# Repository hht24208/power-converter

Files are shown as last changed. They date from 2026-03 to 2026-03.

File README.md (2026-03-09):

# STM32 Kontrollü SEPIC Güç Dönüştürücü (Öğrenci Projesi)

Bu repo, güç elektroniği ve kontrol teorisi konseptlerini birleştirerek pratik bir donanıma dönüştürmeyi amaçlayan kişisel bir mühendislik projesidir. Temel hedef, geniş giriş voltajı aralıklarında çalışabilen, yazılım tabanlı (STM32) PID kontrolüne sahip bir SEPIC dönüştürücünün önce LTspice üzerinde matematiksel sınırlarını görmek, ardından gerçek donanımını inşa etmektir.

## 1. Güç Katı ve Donanım Mimarisi
Aşağıdaki şema, SEPIC topolojisinin güç katını ve temel geri besleme (feedback) yapısını göstermektedir. Sistemi mikrodenetleyici ile güvenli bir şekilde sürebilmek için **TC4427** gate sürücü entegresi kullanıldı. Akım ve gerilim okumaları ise **LM358** op-ampları ile STM32'nin ADC pinlerine uygun seviyelere çekildi.

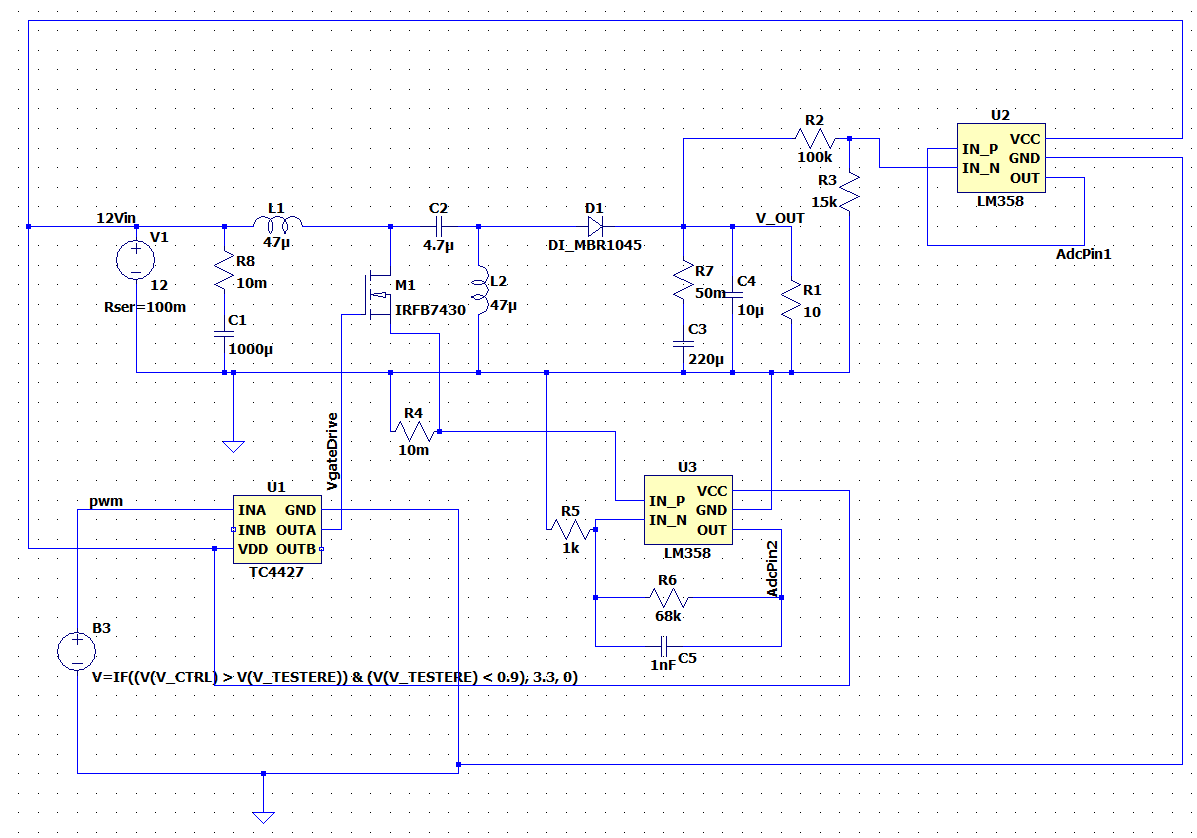
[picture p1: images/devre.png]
SEPIC Devre Şeması


## 2. Matematiksel Modelleme ve Kontrolcü Tasarımı
SEPIC dönüştürücüler 4. dereceden non-lineer sistemler olduğu ve sağ yarı düzlem sıfırı (RHPZ) barındırdığı için, sadece deneme-yanılma ile kontrol edilmeleri oldukça zordur. Bu projede işin teorik kısmına inilerek, sistemin transfer fonksiyonuna uygun bir **Type-II/III Kompansatör** mantığı araştırılmış ve LTspice üzerinde s-domain (Laplace) denklemleriyle modellenmiştir.

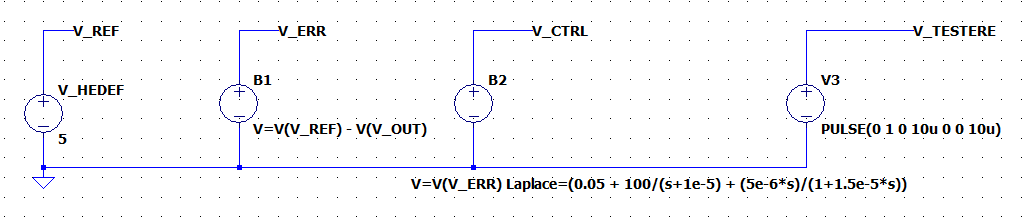
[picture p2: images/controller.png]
PID Kontrolcü ve Laplace Denklemi


## 3. Geçici Hal Yanıtı (Transient Response)
Aşağıdaki simülasyon çıktısında, sisteme aniden 12V giriş (Step Input) uygulandığında donanımın verdiği fiziksel tepki ve PID kontrolcünün davranışı incelenmiştir.
* Simülasyonun ilk milisaniyelerinde, SEPIC topolojisindeki uçan kondansatörün (flying capacitor) dolması sırasında oluşan doğal **Inrush Current (Başlangıç Şoku)** nedeniyle voltaj anlık olarak yükseliyor.
* Kontrolcü bu durumu yakalayarak PWM'i (Duty Cycle) %0'a çekiyor.
* Sistem yaklaşık 11. milisaniyede hedeflediğimiz **5V** seviyesine başarıyla oturarak regülasyonu sağlıyor.

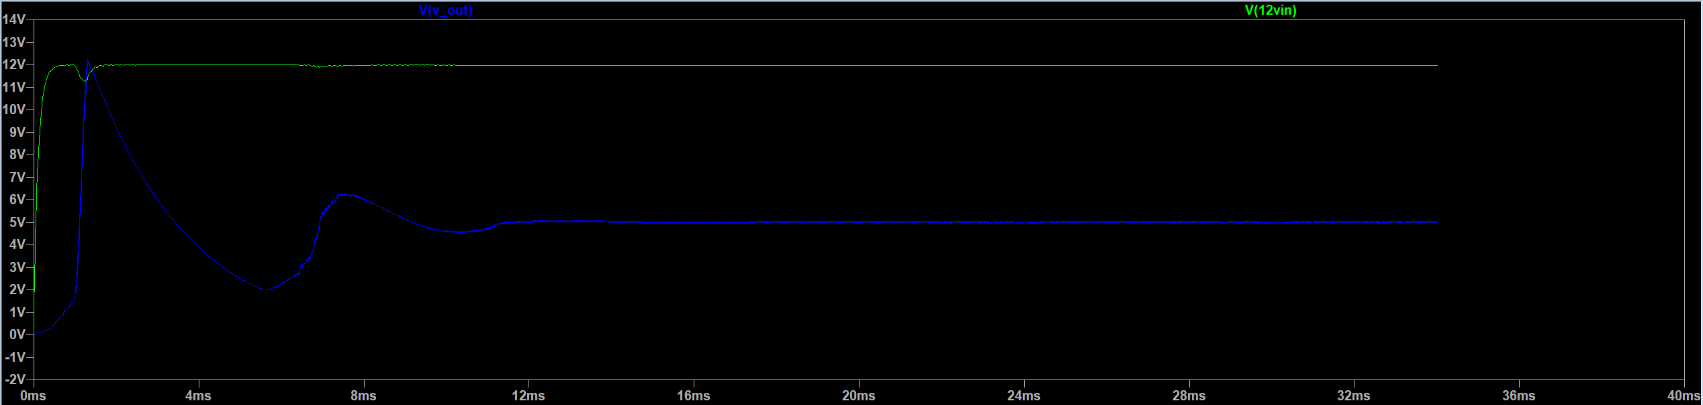
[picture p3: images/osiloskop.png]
Osiloskop Çıktısı - 12V Inrush ve 5V Regülasyonu


---
*Not: Bu simülasyon aşaması, işin "yazılım-donanım takasını" (hardware vs. software trade-off) analiz etmek için yapılmıştır. İlerleyen aşamalarda KiCad ile PCB tasarımı yapılacak ve gerçek dünyadaki komponent toleransları STM32 üzerindeki C tabanlı bir kontrol algoritmasıyla yönetilmeye çalışılacaktır.*

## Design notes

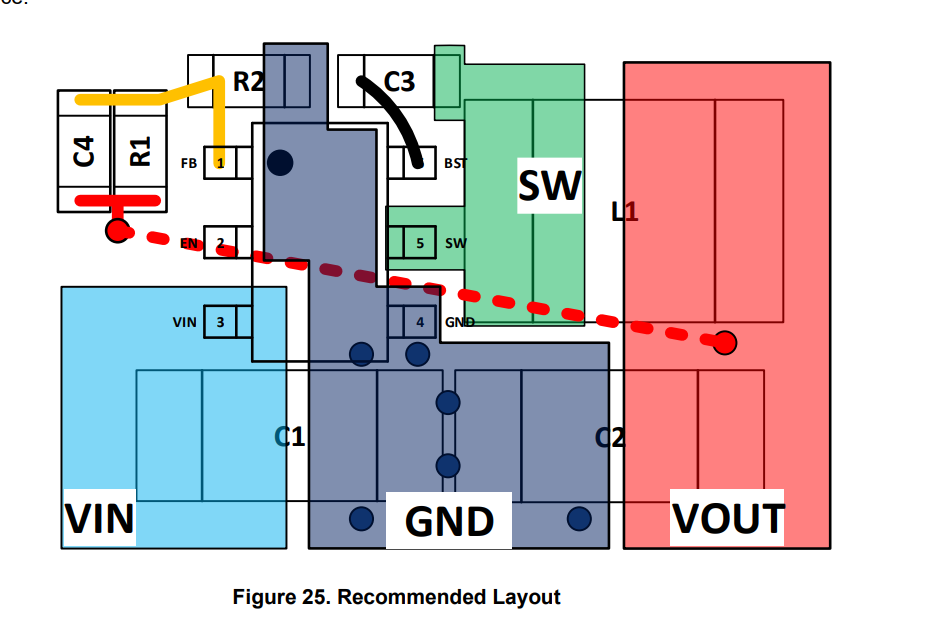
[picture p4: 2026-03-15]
images/Ekran görüntüsü 2026-03-15 152348.png

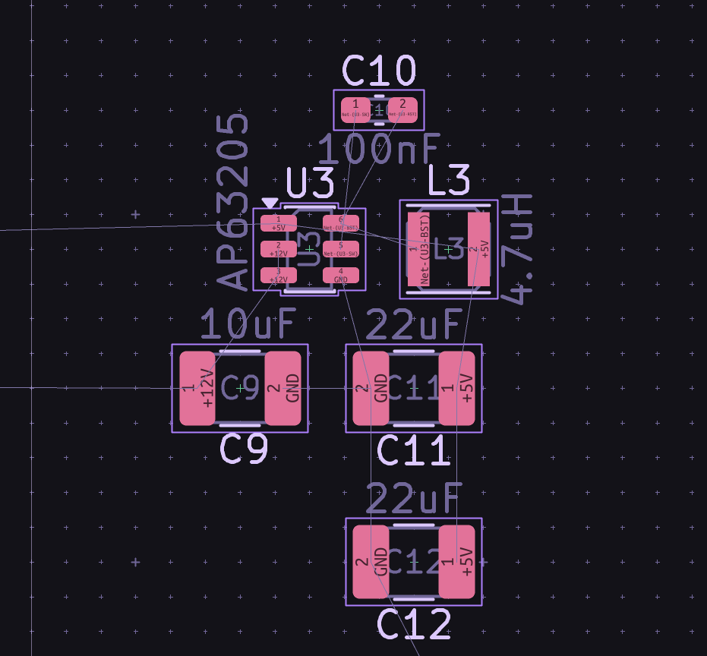
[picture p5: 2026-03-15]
images/Ekran görüntüsü 2026-03-15 152324.png

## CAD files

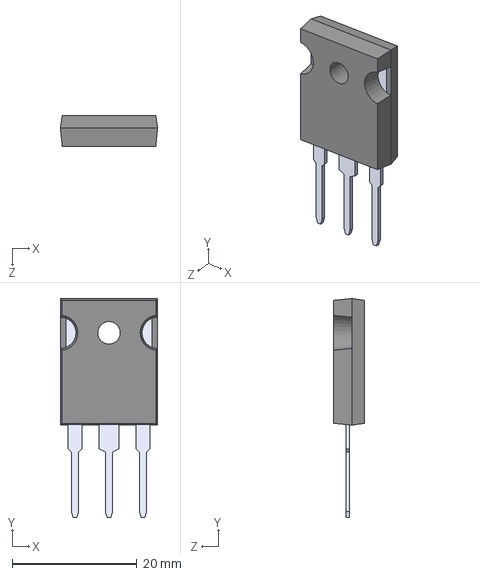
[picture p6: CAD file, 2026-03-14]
IRFB7430PBFCadModel/IRFP7430PBF.step
15.6 x 35.1 x 5.00 mm

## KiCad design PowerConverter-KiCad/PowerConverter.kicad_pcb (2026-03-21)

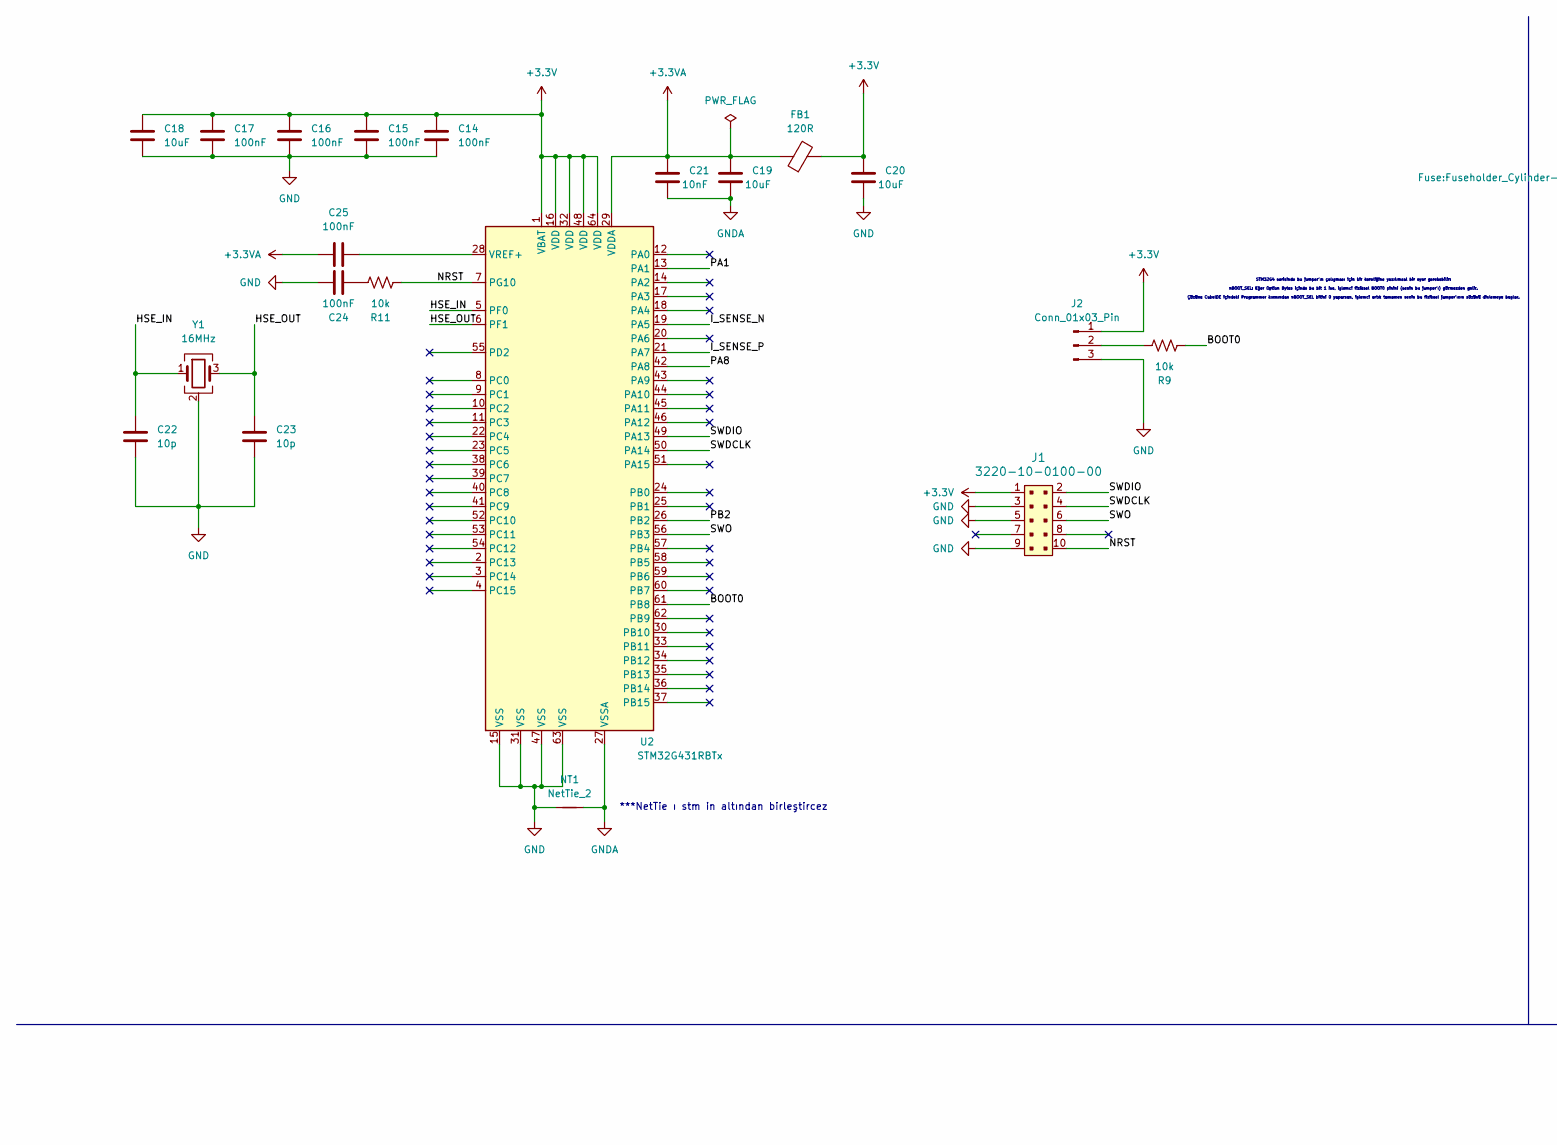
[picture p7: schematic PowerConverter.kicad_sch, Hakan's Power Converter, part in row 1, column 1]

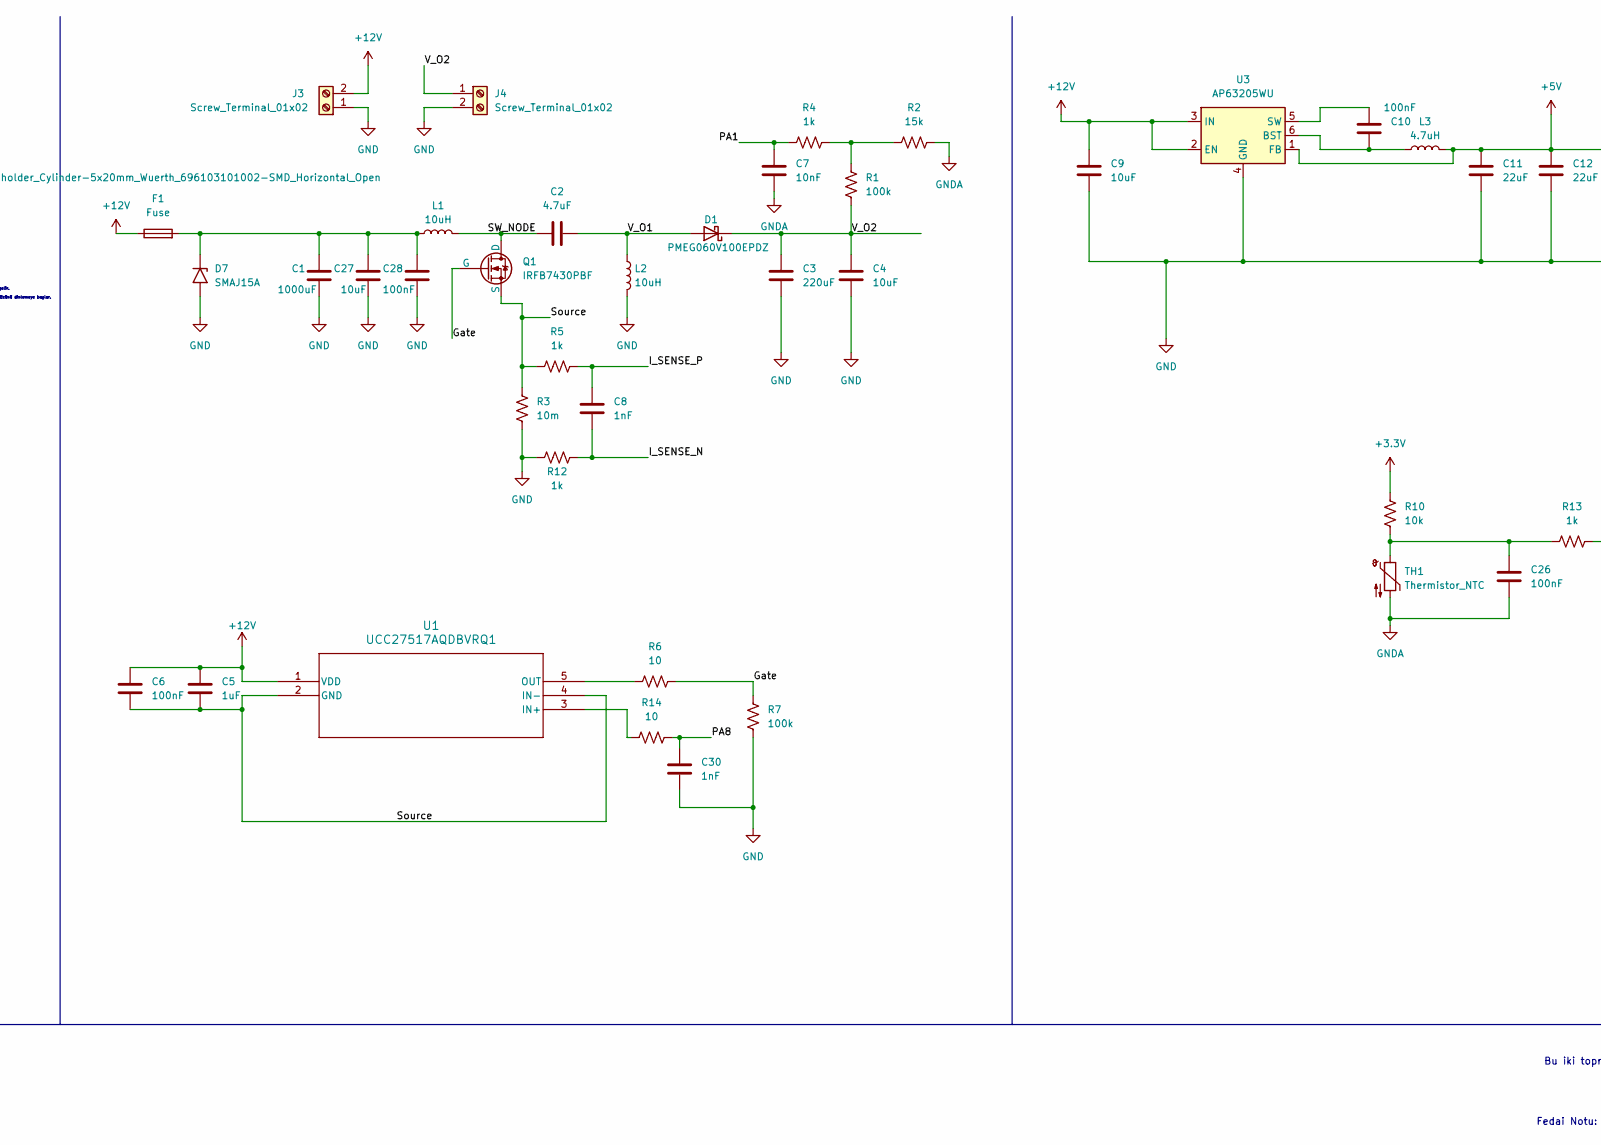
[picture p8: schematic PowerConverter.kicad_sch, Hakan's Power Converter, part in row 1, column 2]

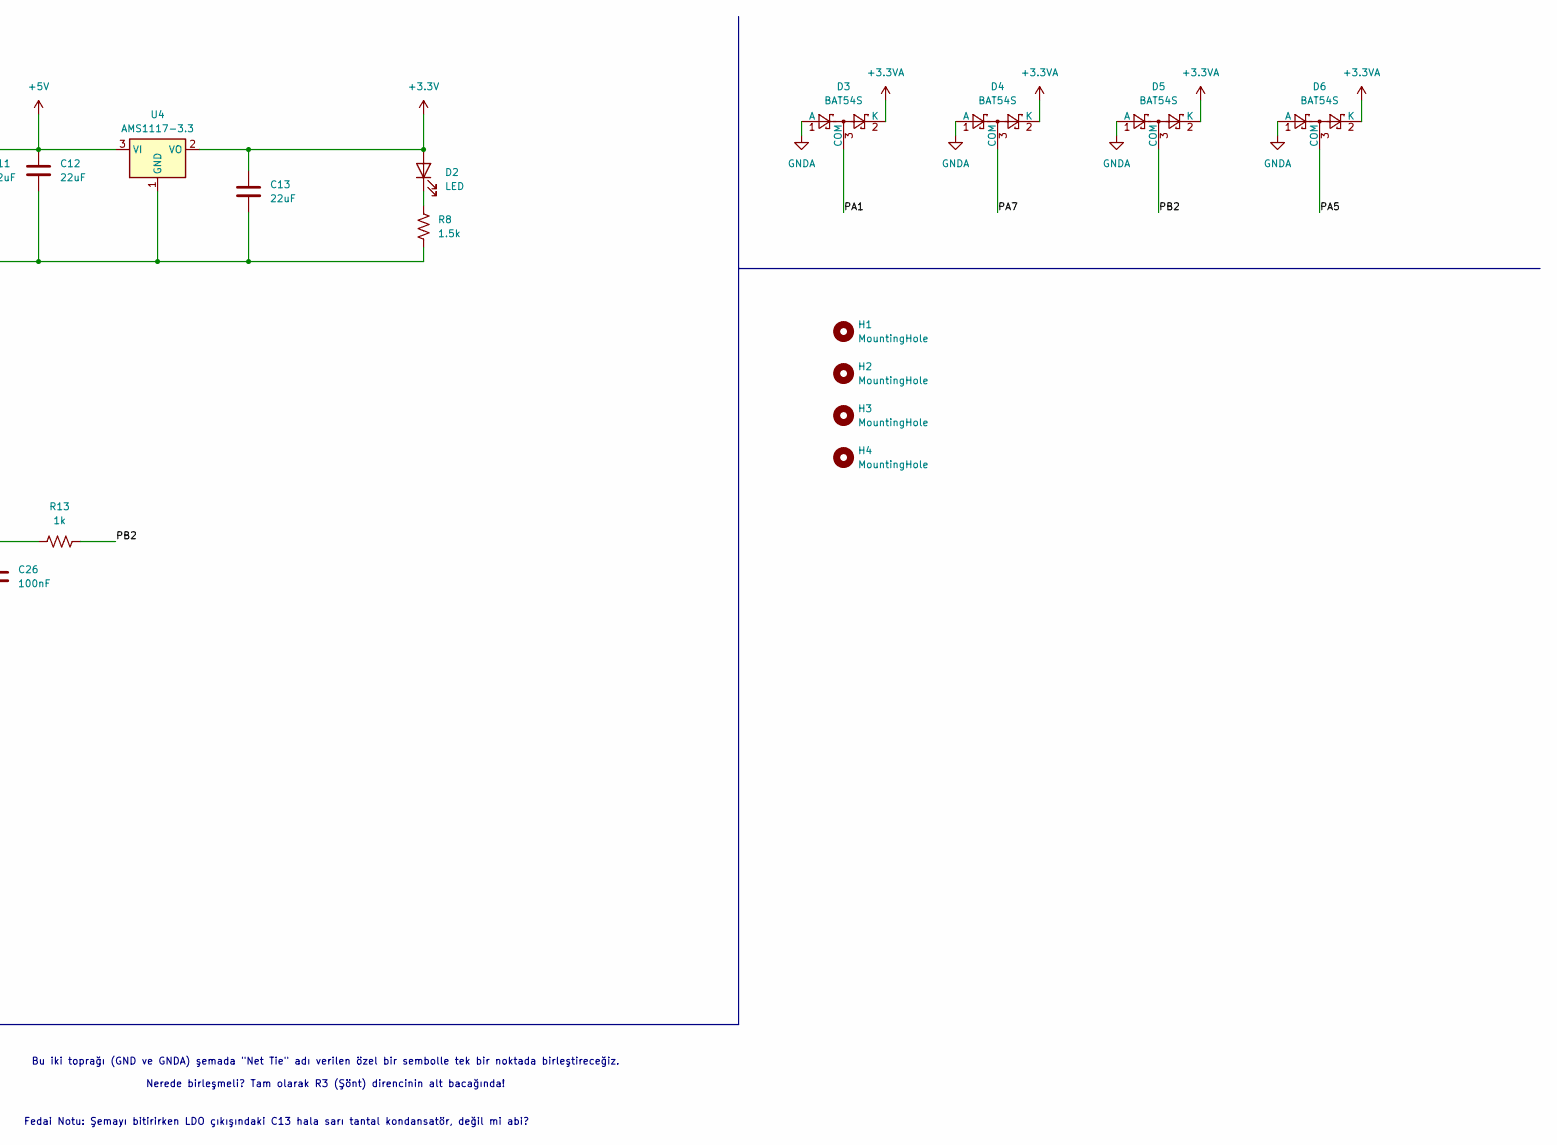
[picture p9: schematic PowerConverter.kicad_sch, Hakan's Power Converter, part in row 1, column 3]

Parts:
C1: 1000uF; CP_Radial_D16.0mm_P7.50mm
C2: 4.7uF; C_1210_3225Metric_Pad1.33x2.70mm_HandSolder
C3: 220uF; CP_Radial_D8.0mm_P5.00mm
C4, C18, C19, C20, C27: 10uF; C_0805_2012Metric_Pad1.18x1.45mm_HandSolder
C5: 1uF; C_0805_2012Metric_Pad1.18x1.45mm_HandSolder
C6, C10, C14, C15, C16, C17, C24, C25, C26, C28: 100nF; C_0603_1608Metric_Pad1.08x0.95mm_HandSolder
C7, C21: 10nF; C_0603_1608Metric_Pad1.08x0.95mm_HandSolder
C8, C30: 1nF; C_0603_1608Metric_Pad1.08x0.95mm_HandSolder
C9: 10uF; C_1210_3225Metric_Pad1.33x2.70mm_HandSolder
C11, C12: 22uF; C_1210_3225Metric_Pad1.33x2.70mm_HandSolder
C13: 22uF; CP_EIA-3528-21_Kemet-B_HandSolder
C22, C23: 10p; C_0603_1608Metric_Pad1.08x0.95mm_HandSolder
D1: PMEG060V100EPDZ; TO-277B
D2: LED; LED_0805_2012Metric_Pad1.15x1.40mm_HandSolder
D3, D4, D5, D6: BAT54S; SOT-23
D7: SMAJ15A; D_SMC
F1: Fuse; Fuseholder_Cylinder-5x20mm_Wuerth_696103101002-SMD_Horizont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
FB1: 120R; L_0603_1608Metric
H1, H2, H3, H4: MountingHole; MountingHole_3.2mm_M3
J1: 3220-10-0100-00; PinHeader_2x5_P1.27mm_Drill.7mm; MPN 3220-10-0100-00; Digi-Key_PN 1175-1627-ND
J2: Conn_01x03_Pin; PinHeader_1x03_P2.54mm_Vertical
J3, J4: Screw_Terminal_01x02; Term_Block_1x2_P5.08MM
L1, L2: 10uH; L_Bourns_SRP1245A
L3: 4.7uH; L_Taiyo-Yuden_NR-30xx
NT1: NetTie_2; NetTie-2_SMD_Pad0.5mm
Q1: IRFB7430PBF; TO-220-3_Vertical
R1, R7: 100k; R_0603_1608Metric_Pad0.98x0.95mm_HandSolder
R2: 15k; R_0603_1608Metric_Pad0.98x0.95mm_HandSolder
R3: 10m; R_2512_6332Metric_Pad1.40x3.35mm_HandSolder
R4, R5, R12, R13: 1k; R_0603_1608Metric_Pad0.98x0.95mm_HandSolder
R6, R14: 10; R_0805_2012Metric_Pad1.20x1.40mm_HandSolder
R8: 1.5k; R_0603_1608Metric_Pad0.98x0.95mm_HandSolder
R9, R10, R11: 10k; R_0603_1608Metric_Pad0.98x0.95mm_HandSolder
TH1: Thermistor_NTC; R_0603_1608Metric_Pad0.98x0.95mm_HandSolder
U1: UCC27517AQDBVRQ1; DBV5_TEX
U2: STM32G431RBTx; LQFP-64_10x10mm_P0.5mm
U3: AP63205WU; TSOT-23-6
U4: AMS1117-3.3; SOT-223-3_TabPin2
Y1: 16MHz; Crystal_SMD_3225-4Pin_3.2x2.5mm

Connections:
+3.3V: C13.1, C14.1, C15.1, C16.1, C17.1, C18.1, C20.1, D2.2 (A), FB1.2, J1.1, J2.1, R10.2, U2.1 (VBAT), U2.16 (VDD), U2.32 (VDD), U2.48 (VDD), U2.64 (VDD), U4.2 (VO)
+3.3VA: C19.1, C21.1, C25.1, D3.2 (K), D4.2 (K), D5.2 (K), D6.2 (K), FB1.1, U2.29 (VDDA)
+5V: C11.1, C12.1, L3.2, U3.1 (FB), U4.3 (VI)
+12V: C5.1, C6.1, C9.1, F1.1, J3.2, U1.1 (VDD), U3.2 (EN), U3.3 (IN)
/BOOT0: R9.2, U2.61 (PB8)
/Gate: Q1.2 (G), R6.2, R7.2
/HSE_IN: C22.1, U2.5 (PF0), Y1.1
/HSE_OUT: C23.1, U2.6 (PF1), Y1.3
/I_SENSE_N: C8.2, R12.2, U2.19 (PA5)
/I_SENSE_P: C8.1, R5.2, U2.21 (PA7)
/NRST: J1.10, R11.2, U2.7 (PG10)
/PA1: C7.1, D3.3 (COM), R4.1, U2.13 (PA1)
/PA5: D6.3 (COM)
/PA7: D4.3 (COM)
/PA8: C30.1, R14.2, U2.42 (PA8)
/PB2: D5.3 (COM), R13.1, U2.26 (PB2)
/SWDCLK: J1.4, U2.50 (PA14)
/SWDIO: J1.2, U2.49 (PA13)
/SWO: J1.6, U2.56 (PB3)
/SW_NODE: C2.1, L1.2, Q1.1 (D)
/Source: C5.2, C6.2, Q1.3 (S), R3.1, R5.1, U1.2 (GND), U1.4 (IN-)
/V_O1: C2.2, D1.2 (A), L2.1
/V_O2: C3.1, C4.1, D1.1 (K), J4.1, R1.2
GND: C1.2, C3.2, C4.2, C9.2, C11.2, C12.2, C13.2, C14.2, C15.2, C16.2, C17.2, C18.2, C20.2, C22.2, C23.2, C24.1, C27.2, C28.2, C30.2, D7.2 (A2), J1.3, J1.5, J1.9, J2.3, J3.1, J4.2, L2.2, NT1.1, R3.2, R7.1, R8.1, R12.1, U2.15 (VSS), U2.31 (VSS), U2.47 (VSS), U2.63 (VSS), U3.4 (GND), U4.1 (GND), Y1.2 (G), Y1.4 (G)
GNDA: C7.2, C19.2, C21.2, C26.2, D3.1 (A), D4.1 (A), D5.1 (A), D6.1 (A), NT1.2, R2.2, TH1.2, U2.27 (VSSA)
unnamed: C24.2, R11.1
unnamed: C26.1, R10.1, R13.2, TH1.1
unnamed: D2.1 (K), R8.2
unnamed: C1.1, C27.1, C28.1, D7.1 (A1), F1.2, L1.1
unnamed: J2.2, R9.1
unnamed: R1.1, R2.1, R4.2
unnamed: R14.1, U1.3 (IN+)
unnamed: R6.1, U1.5 (OUT)
unnamed: C25.2, U2.28 (VREF+)
unnamed: C10.2, L3.1, U3.6 (BST)
unnamed: C10.1, U3.5 (SW)

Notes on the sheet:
***NetTie ı stm in altından birleştircez
Bu iki toprağı (GND ve GNDA) şemada "Net Tie" adı verilen özel bir sembolle tek bir noktada birleştireceğiz. Nerede birleşmeli? Tam olarak R3 (Şönt) direncinin alt bacağında!
STM32G4 serisinde bu jumper'ın çalışması için bir kereliğine yazılımsal bir ayar gerekebilir: nBOOT_SEL: Eğer Option Bytes içinde bu bit 1 ise, işlemci fiziksel BOOT0 pinini (senin bu jumper'ı) görmezden gelir. Çözüm: CubeIDE içindeki Programmer kısmından nBOOT_SEL bitini 0 yaparsan, işlemci artık 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
Fedai Notu: Şemayı bitirirken LDO çıkışındaki C13 hala sarı tantal kondansatör, değil mi abi?

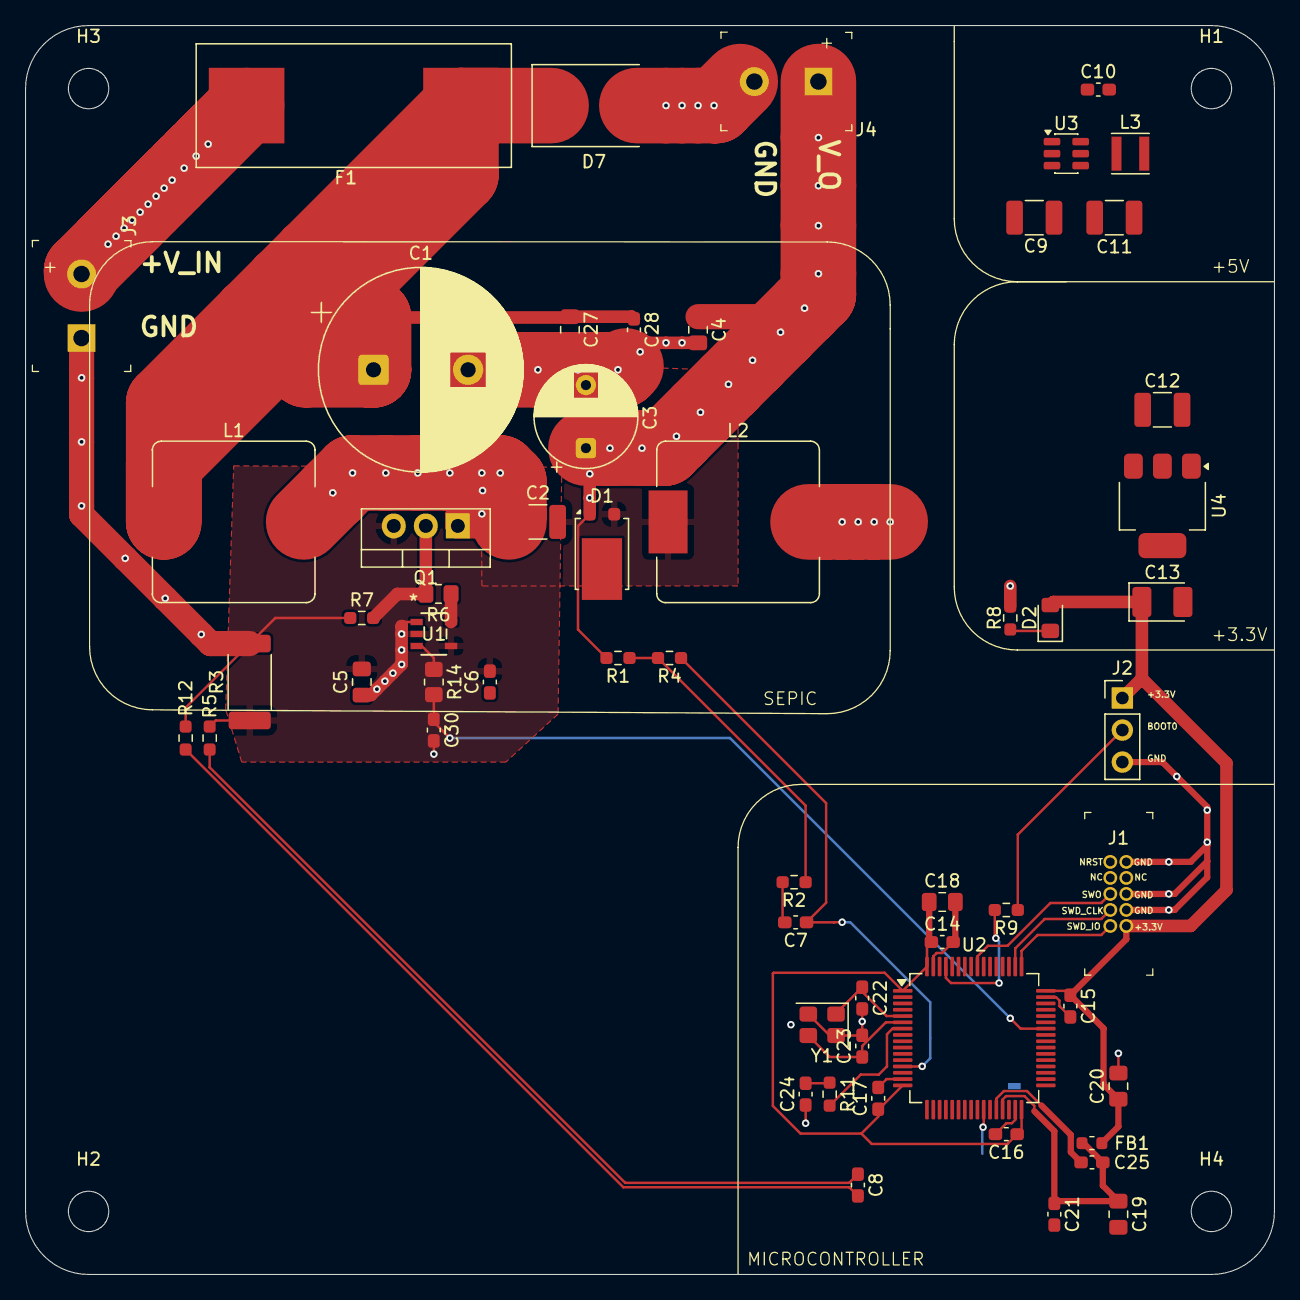
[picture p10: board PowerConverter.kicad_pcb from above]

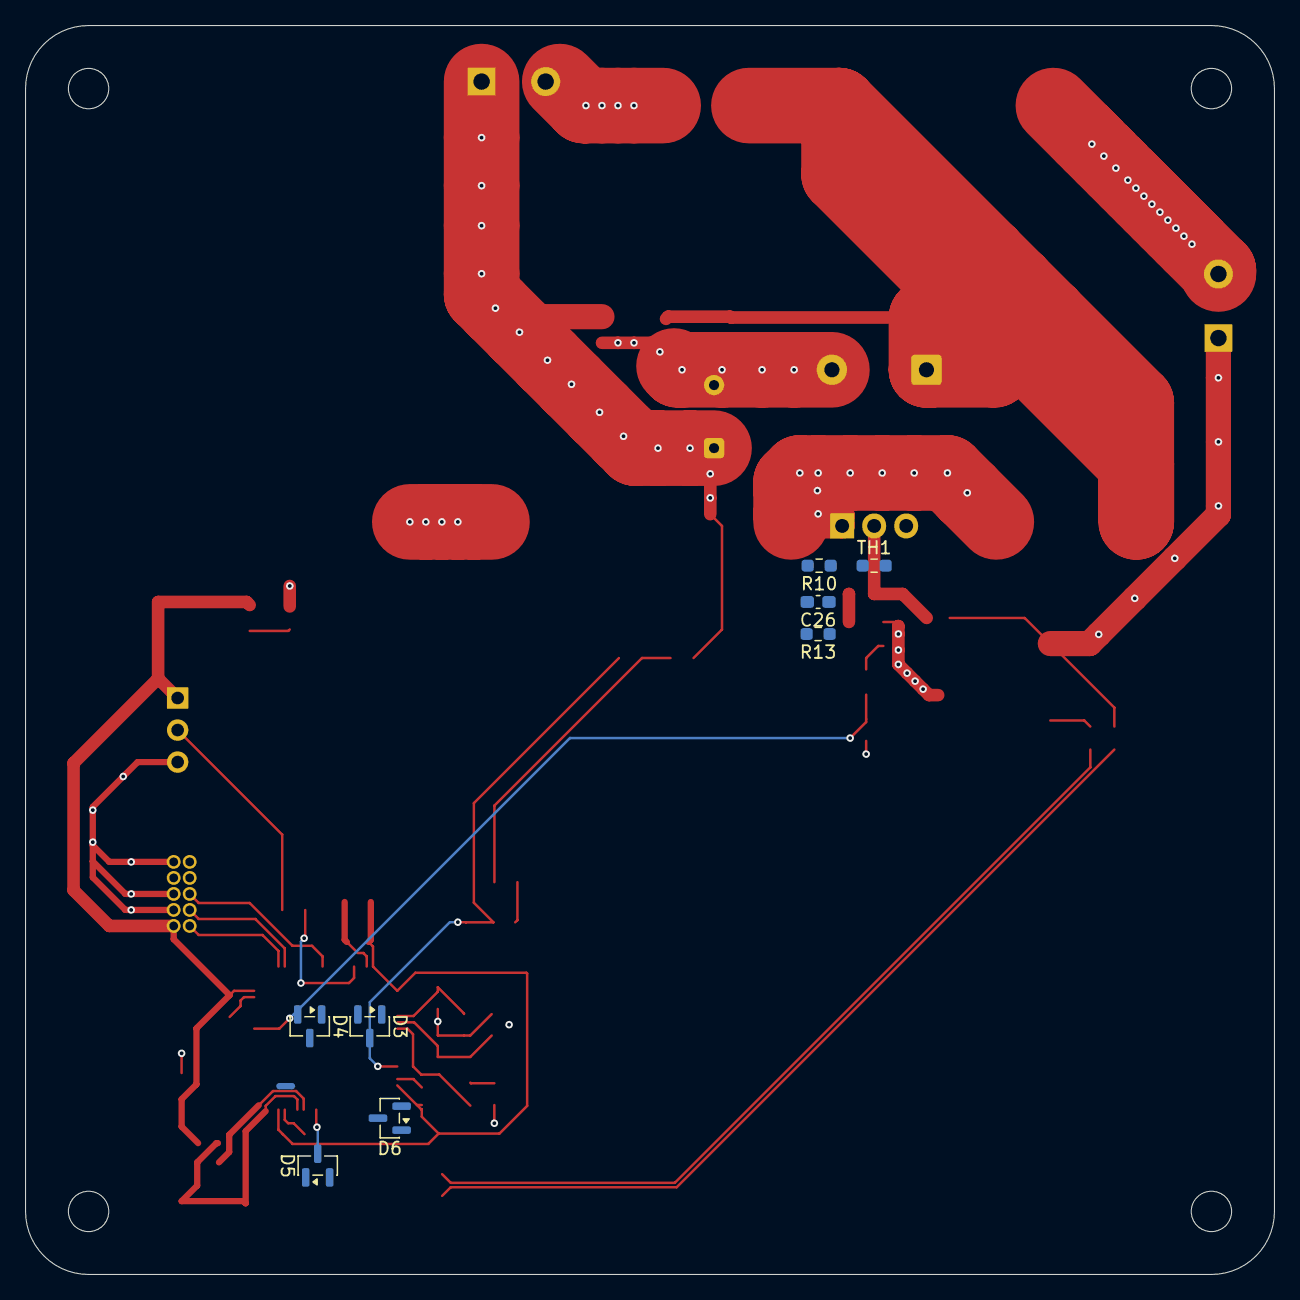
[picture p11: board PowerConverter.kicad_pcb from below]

Board: 4 copper layers, 99.1 x 99.1 mm, 71 parts (9 on the bottom side), 34 nets.

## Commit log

2026-03-08 feat: initial SEPIC design with TC4427 driver and MC34063A aux boost
2026-03-08 hardware: finalized SEPIC power stage, added bulletproof LM358/TC4427 spice models, and implemented active low-pass filtered current/voltage sensing
2026-03-08 feat: SEPIC analog simulation complete with full PID tuning, TC4427 driver, and LM358 current sensing
2026-03-09 feat: SEPIC güç dönüştürücü LTspice simülasyonları, komponent modelleri (LM358, TC4427, IRFB7430) ve PWM jeneratör eklendi
2026-03-09 docs: README guncellendi, LTspice devre mimarisi, PID modeli ve osiloskop sonuclari eklendi
2026-03-09 feat: KiCad PowerConverter projesi baslatildi. TODO: Yarin ilk is Schottky diyot semaya eklenecek.
    [PowerConverter.kicad_pcb, PowerConverter.kicad_sch]
2026-03-11 feat: gate driver eklendi, feedback pinleri (PA1, PA7) ayarlandı. Sırada 12V-3.3V STM beslemesi var.
    [MBR1045.step, PowerConverter.kicad_pcb, PowerConverter.kicad_sch]
2026-03-12 refactor(hardware): Optimize grounding architecture and power stability
    - Fixed AMS1117-3.3 feedback loop to prevent 6.6V overvoltage.
    - Implemented 4-wire Kelvin connection (Net-Tie) for precise 10mOhm current sensing.
    - Added 10-ohm gate resistor to UCC27517 to prevent MOSFET gate ringing.
    - Safely routed UCC27517 IN- pin to GND.
    - Isolated HSE (16MHz) crystal ground strictly to digital GND to protect analog signal integrity.
    - Ensured C13 is a Tantalum capacitor for LDO stability (Mental note preserved).
    [PowerConverter.kicad_sch]
2026-03-12 refactor: STM32G431 işlemci pin eşleşmeleri ve sinyal bütünlüğü iyileştirmeleri
    Bu güncelleme ile donanım mimarisi endüstriyel standartlara getirilmiştir:
    - Kristal (HSE) pinleri, G431 mimarisine uygun olarak PF0/PF1 bacaklarına taşındı.
    - NRST hattı PG10 (Pin 7) üzerine 100nF filtre ile tanımlandı; sistem kararlılığı artırıldı.
    - BOOT0 (PB8) pini 10k pull-down direnci ile mühürlenerek kararsız çalışma modları engellendi.
    - ADC hassasiyeti için VREF+ ve VDDA filtreleme katları revize edildi.
    - Güç katı (5A SEPIC) toprak dönüşleri, analog bölgeden (GNDA) izole edilerek sistem gürültüsü minimize edildi.
    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
    [PowerConverter.kicad_sch]
2026-03-13 feat: SEPIC çevirici Simulink modeli gerçekçi parametrelerle optimize edildi
    - Anahtarlama frekansı 300kHz'e çıkarıldı.
    - Bourns SRP1265A-100M (10uH, 16.5mOhm) bobin modeli entegre edildi.
    - MBR1045 Schottky diyot modeli (Vf ve Ron değerleriyle) eklendi.
    - Yakınsama hatalarını çözmek için 100k sızıntı dirençleri eklendi.
    - ode23t çözücüsüne geçildi ve yerel Backward Euler aktif edildi.
    - Kapasitörlere 30mOhm ESR eklenerek nümerik stabilite sağlandı.
    [PowerConverter.kicad_sch]
2026-03-14 MATLAB analizleri Zero Crossing hataları nedeniyle askıya alındı (14.03.2026). Simülasyon nazıyla uğraşmak yerine fiziksel sistem için KiCad PCB Layout sürecine geçildi.
2026-03-14 Şema ve BOM optimizasyonu tamamlandı. PCB Layout aşamasına geçiliyor.
    [IRFP7430PBF.step, MBR1045.step, PowerConverter.kicad_sch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]
2026-03-15 Layout: Buck ve LDO yerleşimi tamamlandı, sakin ada stratejisi uygulandı
    [PowerConverter.kicad_pcb, PowerConverter.kicad_sch, SK56.step]
2026-03-21 SEPIC v2.0: 4-Layer Stackup, 12V Power Plane on In2, and High Current Via Stitching implemented
    [PowerConverter.kicad_pcb, PowerConverter.kicad_sch]
2026-03-21 Layout update: PA8 bottom layer shielding, U1 RC filter optimization, VDDA daisy-chain routing, and via-in-pad corrections
    [PowerConverter.kicad_pcb, PowerConverter.kicad_sch]
